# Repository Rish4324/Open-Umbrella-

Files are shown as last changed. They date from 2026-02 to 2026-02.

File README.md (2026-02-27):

Hi, This project is done by Group 14, 
Marcus A.
Ethan C.
Nicolas L.
Sahil N.
Rishav S.
Diego S.


We invisioned an umbrealla that is completely open source and can be easily built by the user. This will reduce the waste produced by umbrellas being thrown away through them being more repairable!!

This was done based on our problem statement:
Conventional umbrellas are prone to breaking and are designed to be unrepairable, leading to premature disposal when even a single component is damaged. While niche repairable options exist, they are often prohibitively expensive and lack the ability to adapt to different use cases.

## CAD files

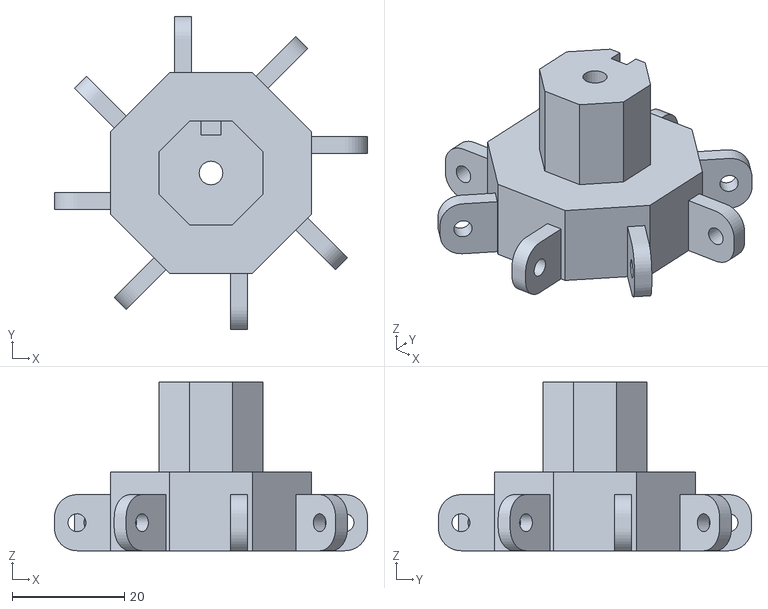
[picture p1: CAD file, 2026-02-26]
Open Umbrella/Top x1.stl
55.7 x 55.7 x 30.0

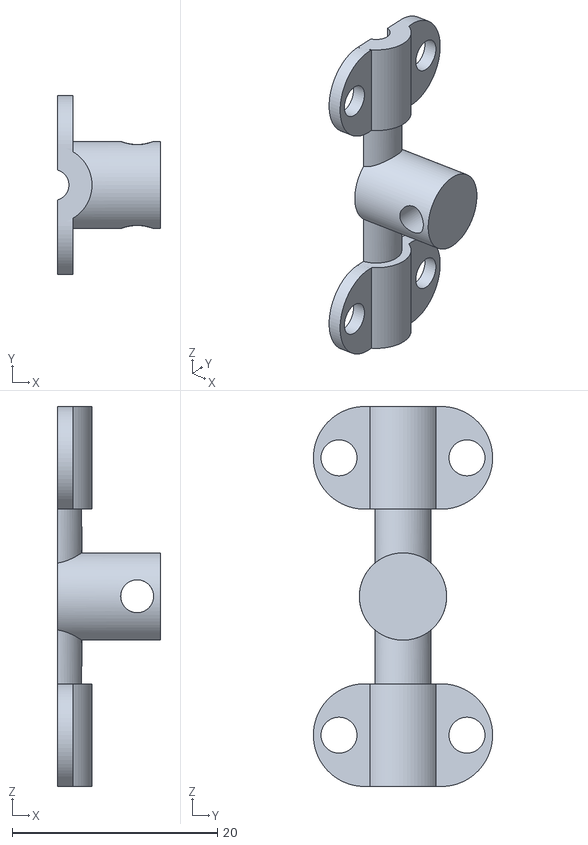
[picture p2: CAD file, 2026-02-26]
Open Umbrella/Canopy Midpoint Tops x8.stl
10.0 x 17.5 x 37.0

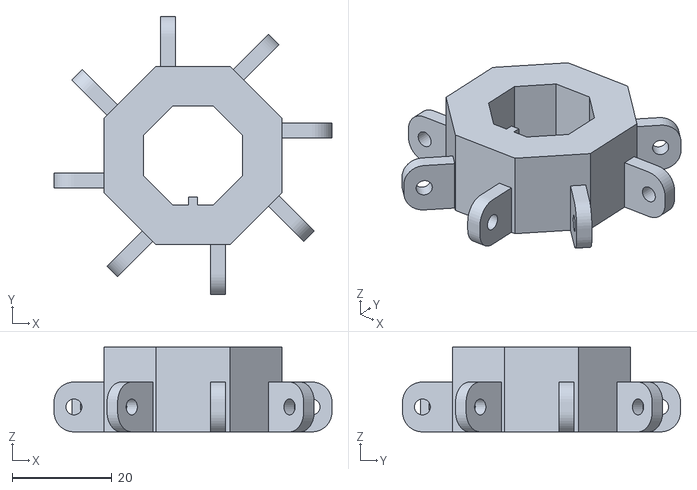
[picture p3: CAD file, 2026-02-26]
Open Umbrella/Collar x1.stl
55.7 x 55.7 x 17.0

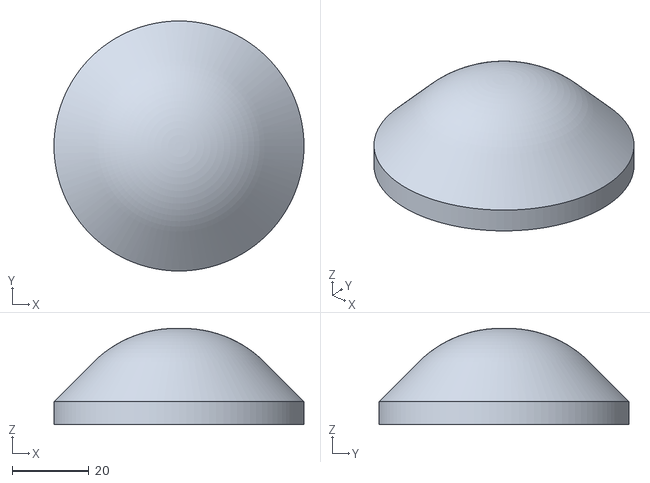
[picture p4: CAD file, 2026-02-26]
Open Umbrella/Cap x1.stl
65.0 x 65.0 x 25.0

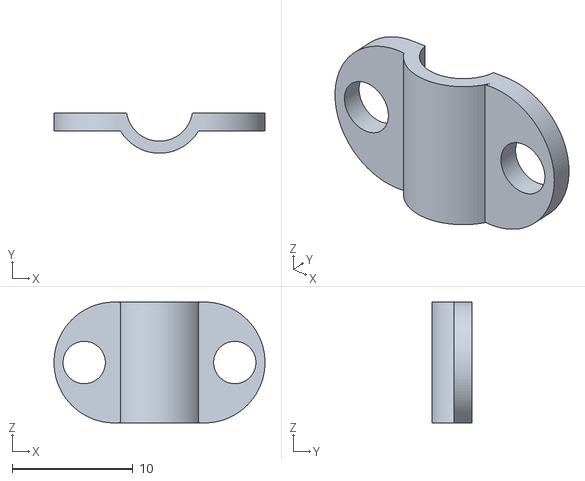
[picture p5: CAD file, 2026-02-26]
Open Umbrella/Canopy Midpoint Clamps x16.stl
17.5 x 3.35 x 10.0

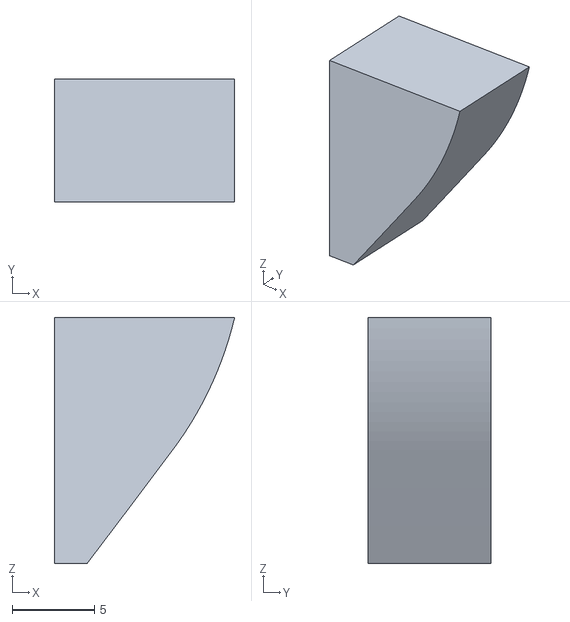
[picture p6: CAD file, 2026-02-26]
Open Umbrella/Spring bit x1.stl
11.0 x 7.50 x 15.0

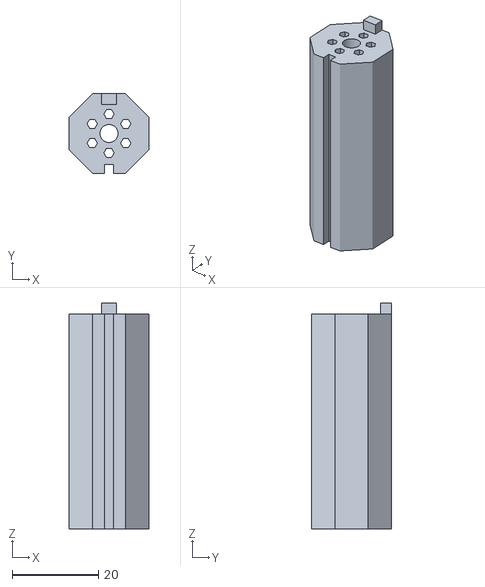
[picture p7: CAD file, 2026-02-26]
Open Umbrella/Base 9x.stl
18.5 x 18.5 x 52.5

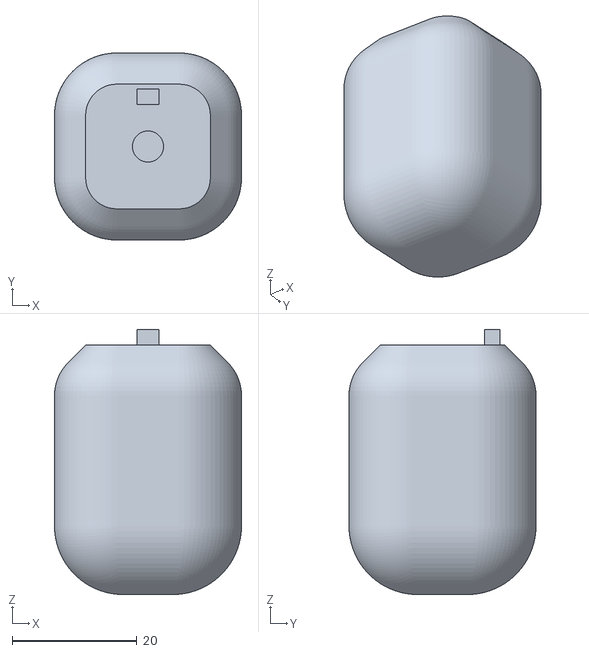
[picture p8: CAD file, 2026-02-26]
Open Umbrella/Handle x1.stl
30.0 x 30.0 x 42.5

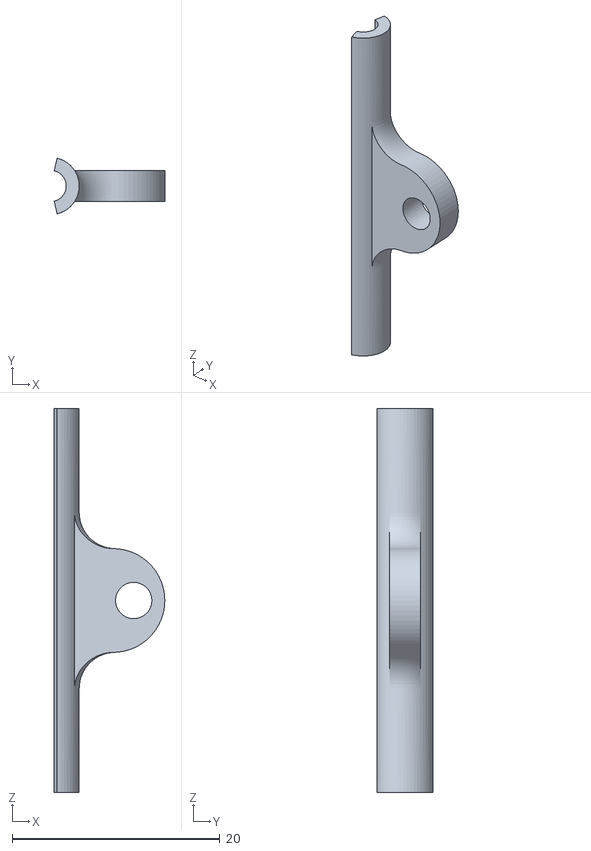
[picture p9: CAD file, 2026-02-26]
Open Umbrella/Canopy Midpoint Bottom x8.stl
10.7 x 5.36 x 37.0

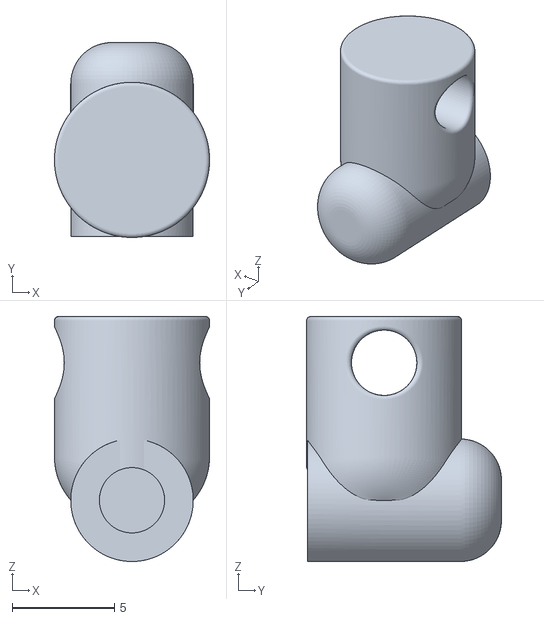
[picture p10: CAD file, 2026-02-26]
Open Umbrella/Canopy Rod Ends x8.stl
7.60 x 9.55 x 12.0

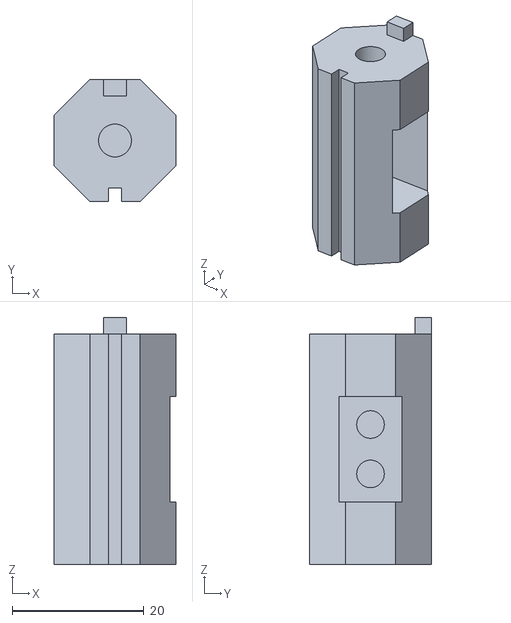
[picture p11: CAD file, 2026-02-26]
Open Umbrella/Spring base x1.stl
18.5 x 18.5 x 37.5

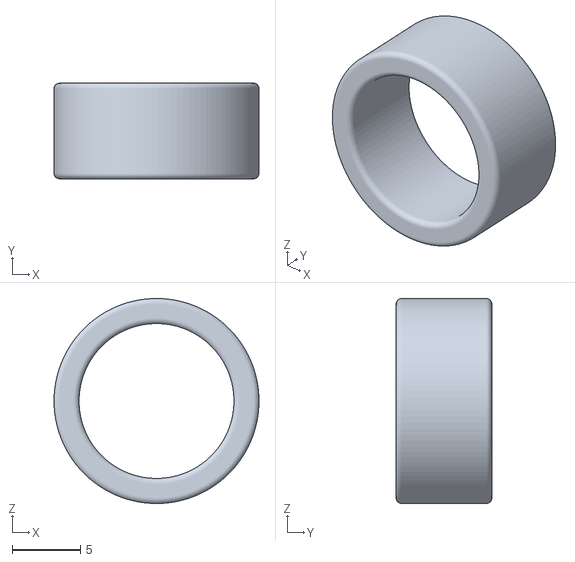
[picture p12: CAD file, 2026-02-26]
Open Umbrella/O ring Cylinders (Outside) x8.stl
15.0 x 7.00 x 15.0

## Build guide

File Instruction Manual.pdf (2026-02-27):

## List of Components:

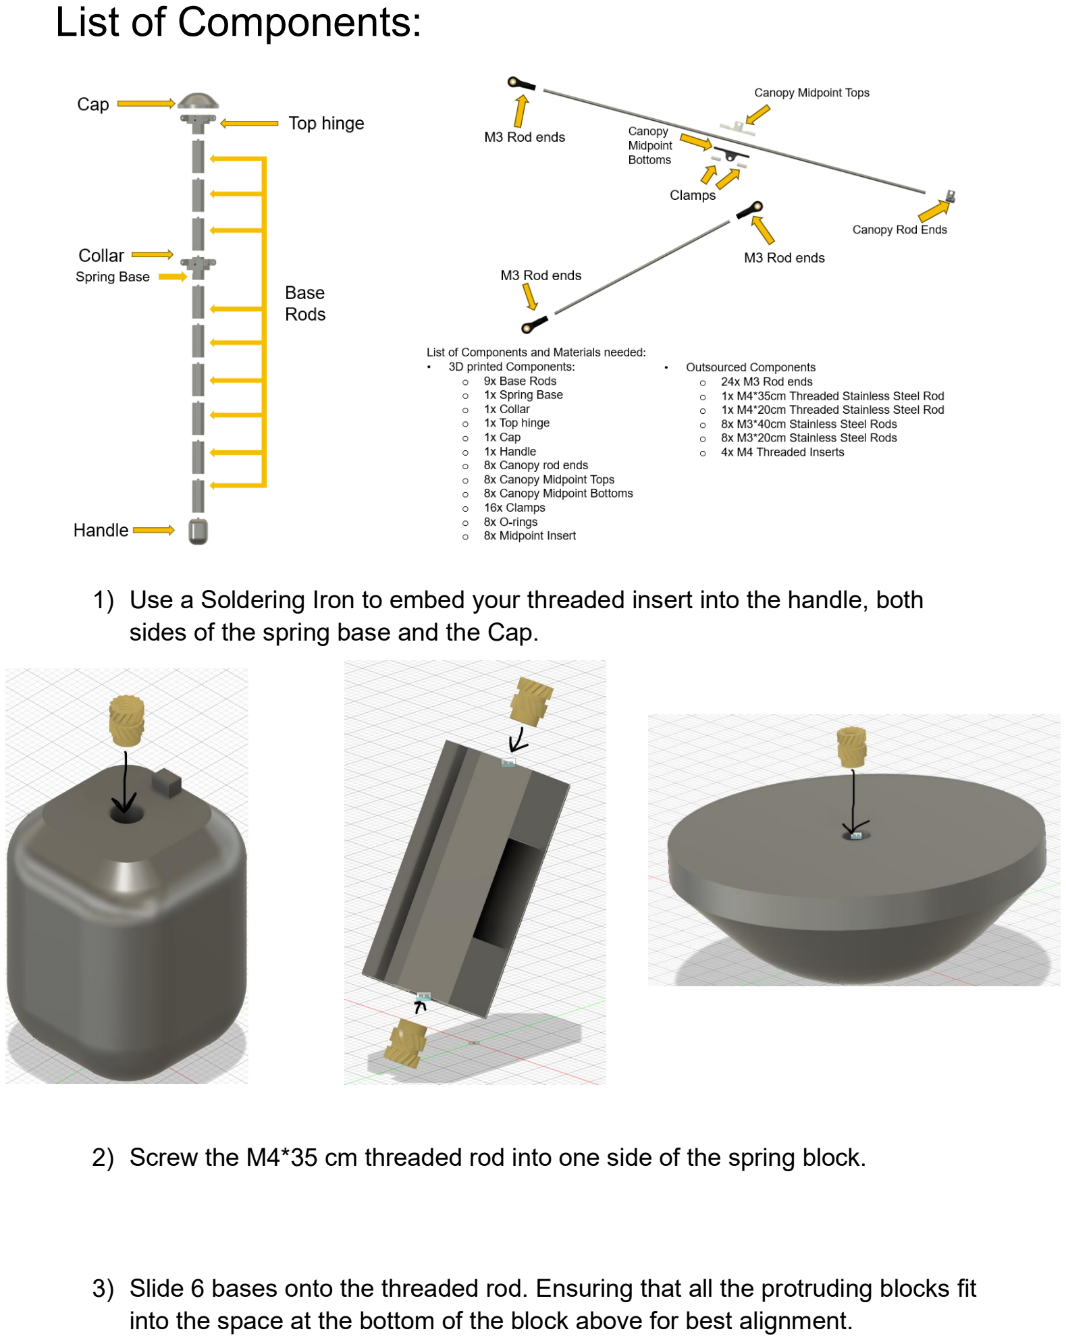
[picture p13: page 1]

1) Use a Soldering Iron to embed your threaded insert into the handle, both sides of the spring base and the Cap.
2) Screw the M4*35 cm threaded rod into one side of the spring block.
3) Slide 6 bases onto the threaded rod. Ensuring that all the protruding blocks fit into the space at the bottom of the block above for best alignment.

4) Screw the handle into the bottom of the threaded rod. It should look something like this.

5) Screw the M4*20cm rod into the other side of the Spring base and slide your remaining three bases and the top into the rod. Ensuring the side with the hinges is towards the top.

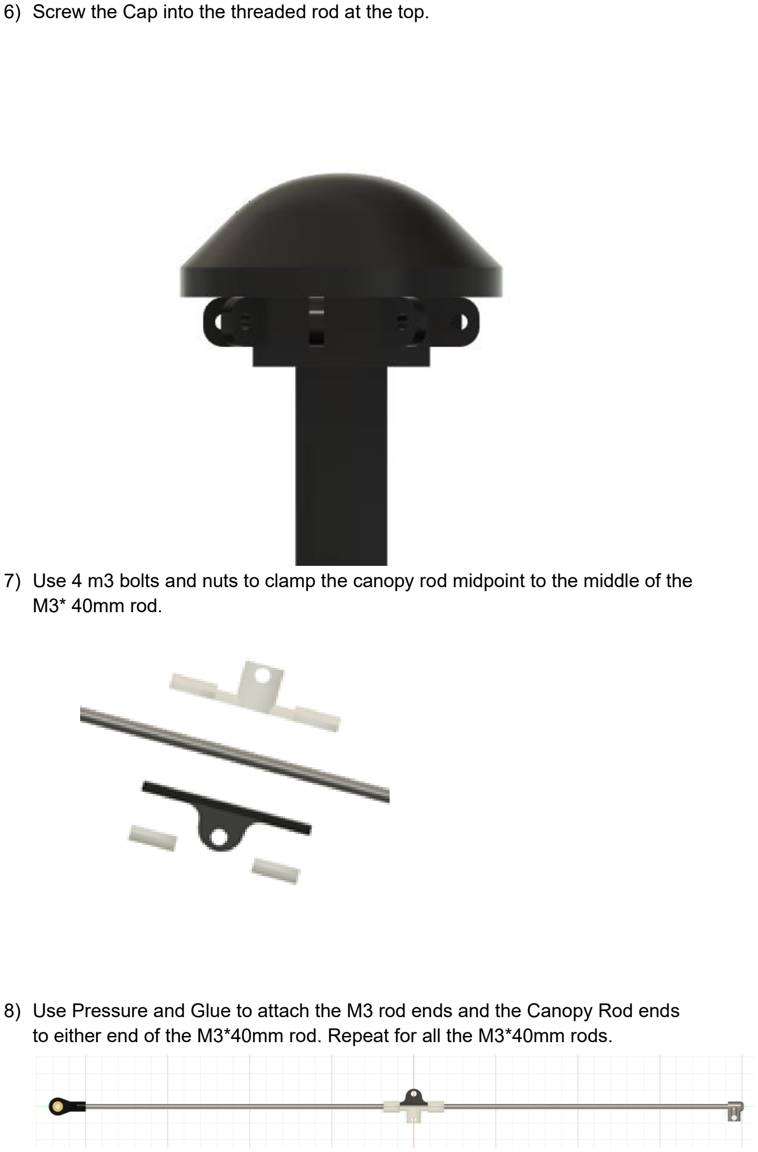
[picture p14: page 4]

6) Screw the Cap into the threaded rod at the top.
7) Use 4 m3 bolts and nuts to clamp the canopy rod midpoint to the middle of the M3* 40mm rod.
8) Use Pressure and Glue to attach the M3 rod ends and the Canopy Rod ends to either end of the M3*40mm rod. Repeat for all the M3*40mm rods.

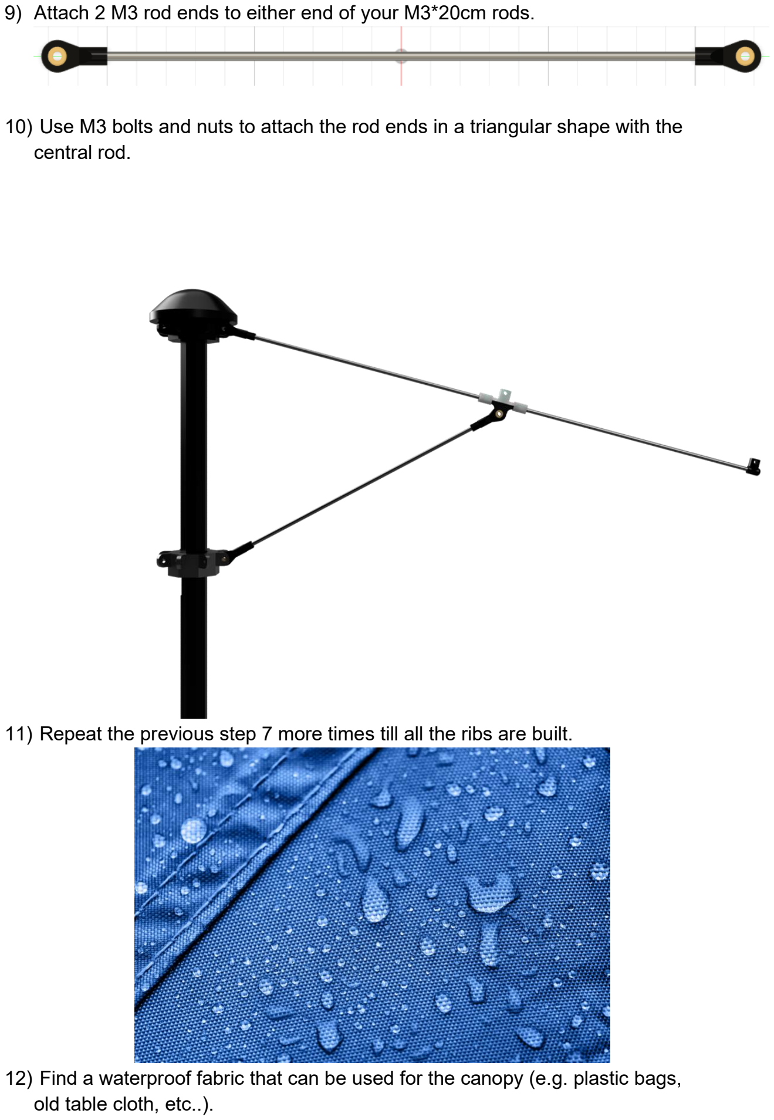
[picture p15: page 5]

9) Attach 2 M3 rod ends to either end of your M3*20cm rods.
10) Use M3 bolts and nuts to attach the rod ends in a triangular shape with the central rod.
11) Repeat the previous step 7 more times till all the ribs are built.
12) Find a waterproof fabric that can be used for the canopy (e.g. plastic bags, old table cloth, etc..).

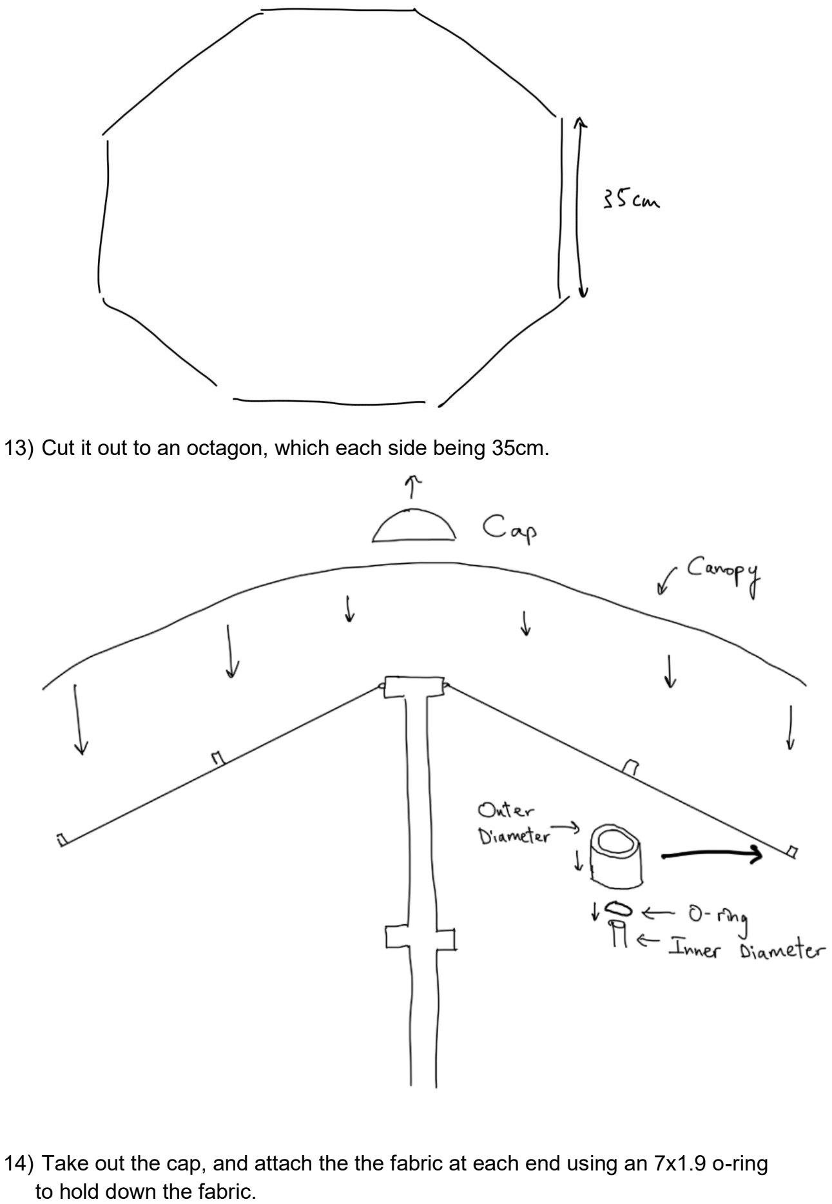
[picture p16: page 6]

13) Cut it out to an octagon, which each side being 35cm.
14) Take out the cap, and attach the the fabric at each end using an 7x1.9 o-ring to hold down the fabric.

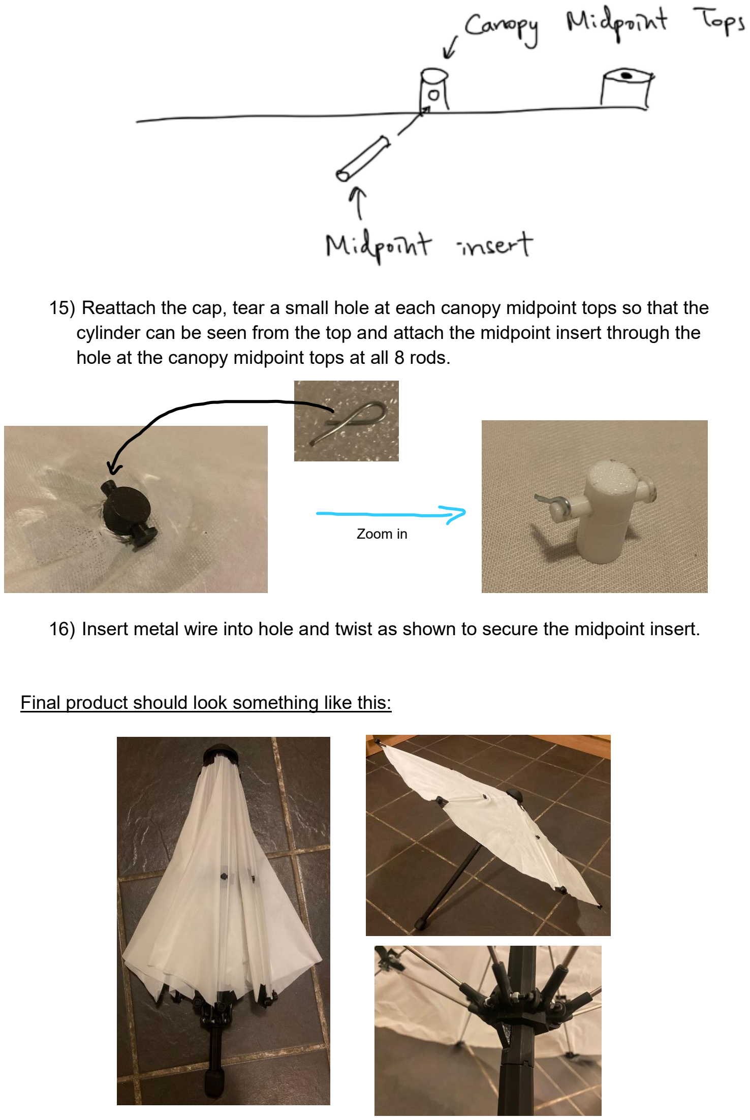
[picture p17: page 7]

15) Reattach the cap, tear a small hole at each canopy midpoint tops so that the cylinder can be seen from the top and attach the midpoint insert through the hole at the canopy midpoint tops at all 8 rods.
16) Insert metal wire into hole and twist as shown to secure the midpoint insert.

Final product should look something like this:

Zoom in
